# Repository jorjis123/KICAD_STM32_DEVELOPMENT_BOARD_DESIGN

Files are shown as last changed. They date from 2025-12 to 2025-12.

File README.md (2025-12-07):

Core MCU: STM32 with access to essential debug/programming interfaces (SWD/SWO/NRST, UART, I2C).

🔹 Power: USB input and dedicated 12V jack, with on-board buck converter for stable 3.3V supply.

🔹 Connectivity: Breakout headers for easy prototyping.

🔹 Layout focus: Optimized ground plane distribution, decoupling capacitors placed for noise reduction, and routing for signal integrity.

🔹 Applications: Ideal for embedded firmware development, educational use, and rapid prototyping.

This project gave me great hands-on experience in schematic capture, PCB layout, power distribution, and embedded hardware design best practices.

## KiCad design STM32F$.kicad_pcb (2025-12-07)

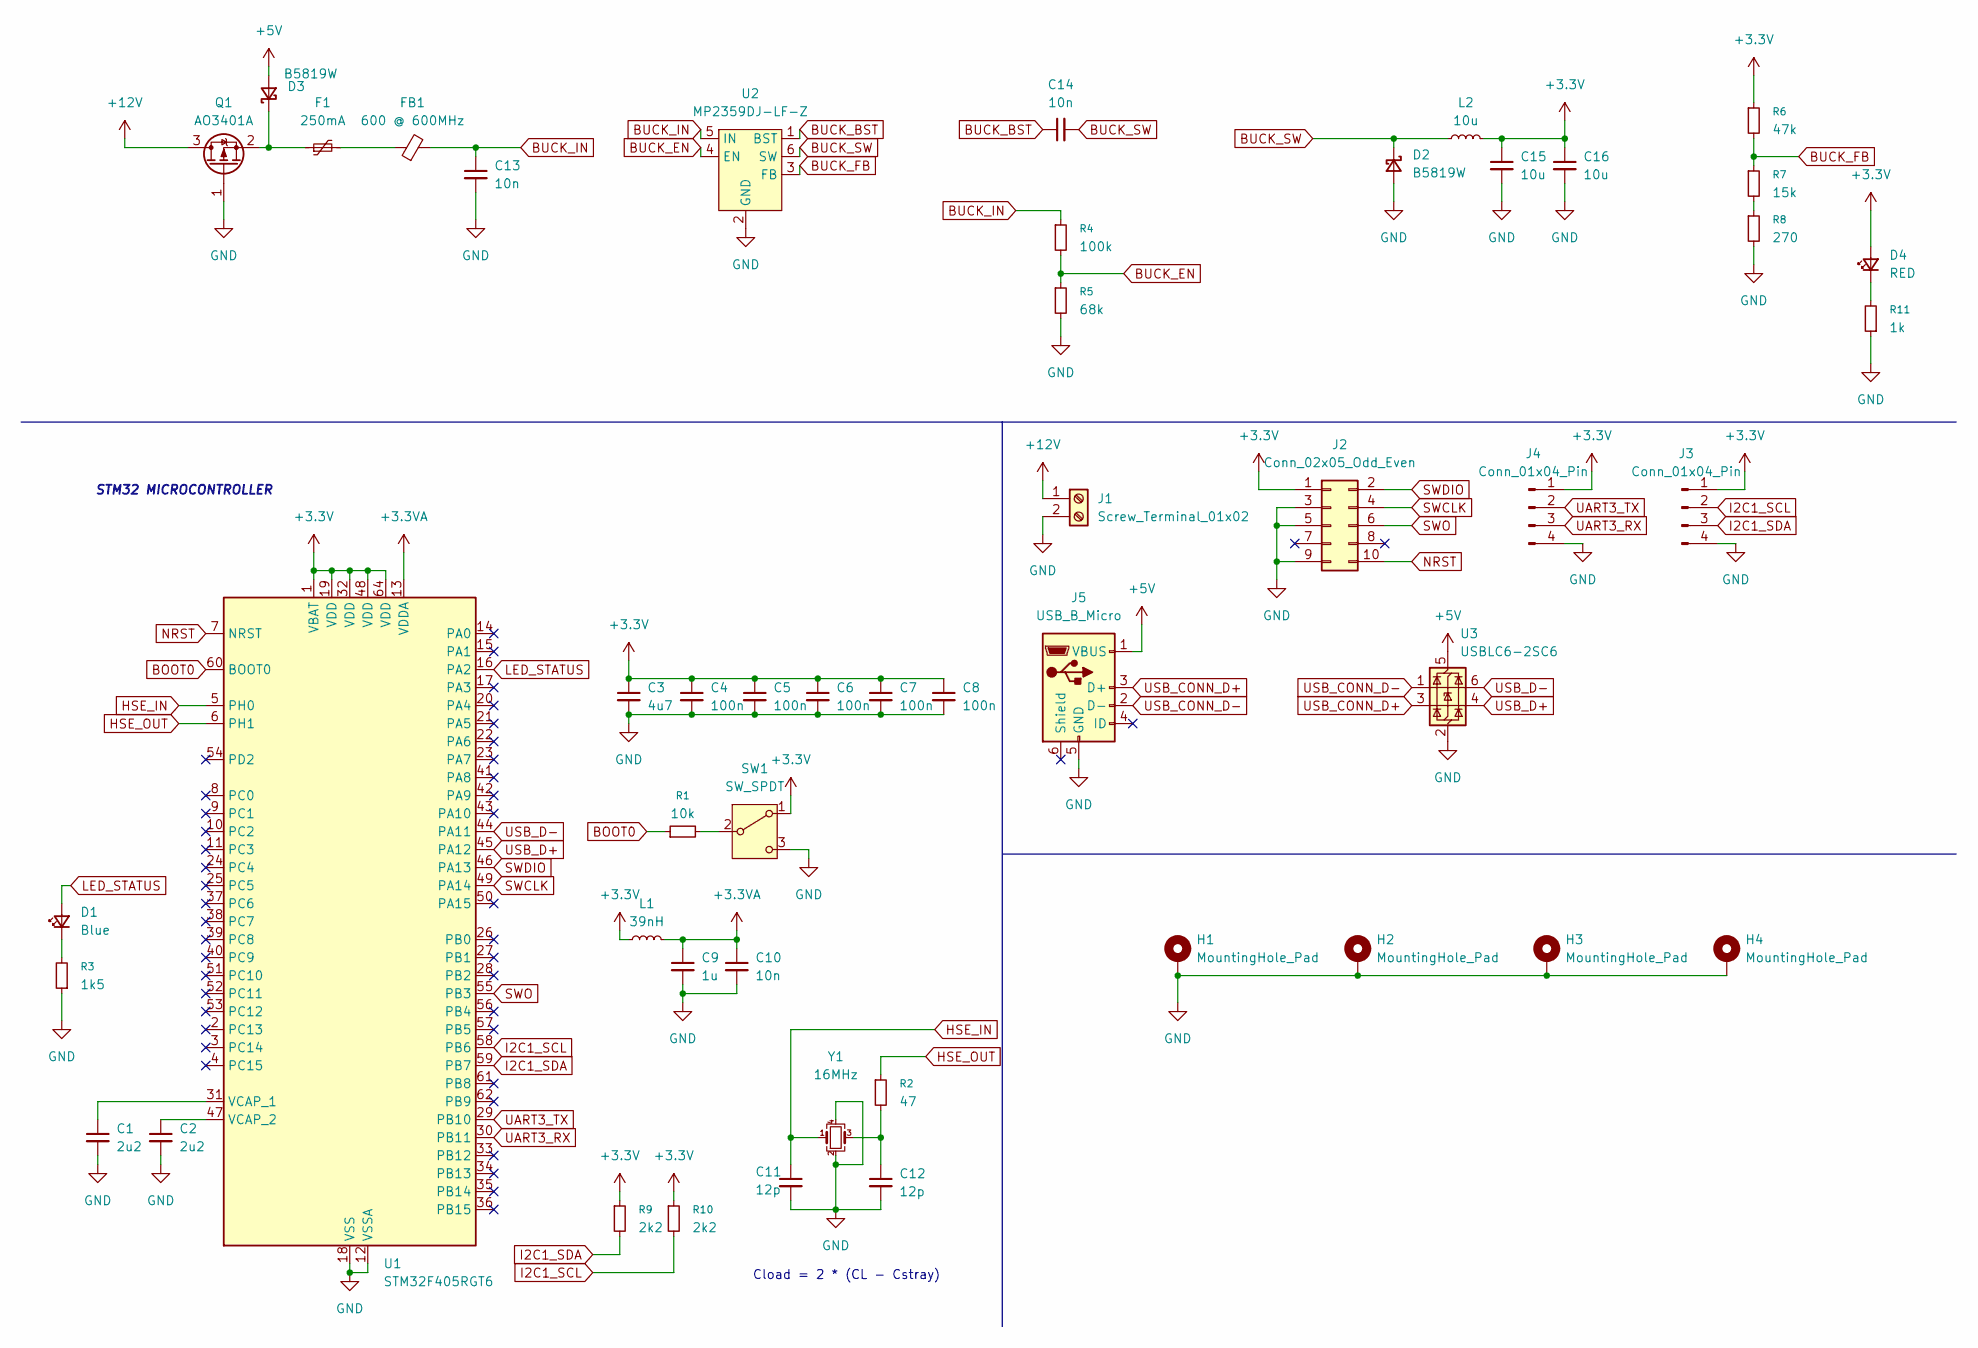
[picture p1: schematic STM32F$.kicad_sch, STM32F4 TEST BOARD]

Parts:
C1, C2: 2u2; C_0603_1608Metric
C3: 4u7; C_0603_1608Metric
C4, C5, C6, C7, C8: 100n; C_0402_1005Metric
C9: 1u; C_0402_1005Metric
C10: 10n; C_0402_1005Metric
C11, C12: 12p; C_0402_1005Metric
C13, C14: 10n; C_0603_1608Metric
C15, C16: 10u; C_1206_3216Metric
D1: Blue; LED_0603_1608Metric
D2, D3: B5819W; D_SOD-123
D4: RED; LED_0603_1608Metric
F1: 250mA; Fuse_1206_3216Metric
FB1: 600 @ 600MHz; L_0805_2012Metric
H1, H2, H3, H4: MountingHole_Pad; MountingHole_4.3mm_M4_Pad_Via
J1: Screw_Terminal_01x02; TerminalBlock_Phoenix_PT-1,5-2-3.5-H_1x02_P3.50mm_Horizontal
J2: Conn_02x05_Odd_Even; PinSocket_2x05_P1.27mm_Vertical_SMD
J3, J4: Conn_01x04_Pin; PinHeader_1x04_P1.00mm_Vertical
J5: USB_B_Micro; USB_Micro-B_Molex_47346-0001
L1: 39nH; L_0402_1005Metric
L2: 10u; L_Sunlord_SWPA8040S
Q1: AO3401A; SOT-23
R1: 10k; R_0603_1608Metric
R2: 47; R_0402_1005Metric
R3: 1k5; R_0603_1608Metric
R4: 100k; R_0402_1005Metric
R5: 68k; R_0402_1005Metric
R6: 47k; R_0402_1005Metric
R7: 15k; R_0603_1608Metric
R8: 270; R_0402_1005Metric
R9, R10: 2k2; R_0402_1005Metric
R11: 1k; R_0402_1005Metric
SW1: SW_SPDT; SW_SPDT_PCM12
U1: STM32F405RGT6; LQFP-64_10x10mm_P0.5mm
U2: MP2359DJ-LF-Z; SOT-23-6
U3: USBLC6-2SC6; SOT-23-6
Y1: 16MHz; Crystal_SMD_3225-4Pin_3.2x2.5mm

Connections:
+3.3V: C3.1, C4.1, C5.1, C6.1, C7.1, C8.1, C15.1, C16.1, D4.2 (A), J2.1, J3.1, J4.1, L1.1, L2.2, R6.1, R9.1, R10.1, SW1.1 (A), U1.1 (VBAT), U1.19 (VDD), U1.32 (VDD), U1.48 (VDD), U1.64 (VDD)
+3.3VA: C9.1, C10.1, L1.2, U1.13 (VDDA)
+5V: D3.2 (A), J5.1 (VBUS), U3.5 (VBUS)
+12V: J1.1, Q1.3 (D)
BOOT0: R1.1, U1.60 (BOOT0)
BUCK_BST: C14.1, U2.1 (BST)
BUCK_EN: R4.2, R5.1, U2.4 (EN)
BUCK_FB: R6.2, R7.1, U2.3 (FB)
BUCK_IN: C13.1, FB1.2, R4.1, U2.5 (IN)
BUCK_SW: C14.2, D2.1 (K), L2.1, U2.6 (SW)
GND: C1.2, C2.2, C3.2, C4.2, C5.2, C6.2, C7.2, C8.2, C9.2, C10.2, C11.2, C12.2, C13.2, C15.2, C16.2, D2.2 (A), H1.1, H2.1, H3.1, H4.1, J1.2, J2.3, J2.5, J2.9, J3.4, J4.4, J5.5 (GND), Q1.1 (G), R3.1, R5.2, R8.2, R11.1, SW1.3 (C), U1.12 (VSSA), U1.18 (VSS), U1.63 (VSS), U2.2 (GND), U3.2 (GND), Y1.2, Y1.4
HSE_IN: C11.1, U1.5 (PH0), Y1.1
HSE_OUT: R2.1, U1.6 (PH1)
I2C1_SCL: J3.2, R10.2, U1.58 (PB6)
I2C1_SDA: J3.3, R9.2, U1.59 (PB7)
LED_STATUS: D1.2 (A), U1.16 (PA2)
NRST: J2.10, U1.7 (NRST)
unnamed: C12.1, R2.2, Y1.3
unnamed: D1.1 (K), R3.2
unnamed: D3.1 (K), F1.1, Q1.2 (S)
unnamed: D4.1 (K), R11.2
unnamed: F1.2, FB1.1
unnamed: R7.2, R8.1
unnamed: R1.2, SW1.2 (B)
unnamed: C1.1, U1.31 (VCAP_1)
unnamed: C2.1, U1.47 (VCAP_2)
SWCLK: J2.4, U1.49 (PA14)
SWDIO: J2.2, U1.46 (PA13)
SWO: J2.6, U1.55 (PB3)
UART3_RX: J4.3, U1.30 (PB11)
UART3_TX: J4.2, U1.29 (PB10)
USB_CONN_D+: J5.3 (D+), U3.3 (I/O2)
USB_CONN_D-: J5.2 (D-), U3.1 (I/O1)
USB_D+: U1.45 (PA12), U3.4 (I/O2)
USB_D-: U1.44 (PA11), U3.6 (I/O1)

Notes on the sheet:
STM32 MICROCONTROLLER
Cload = 2 * (CL - Cstray)

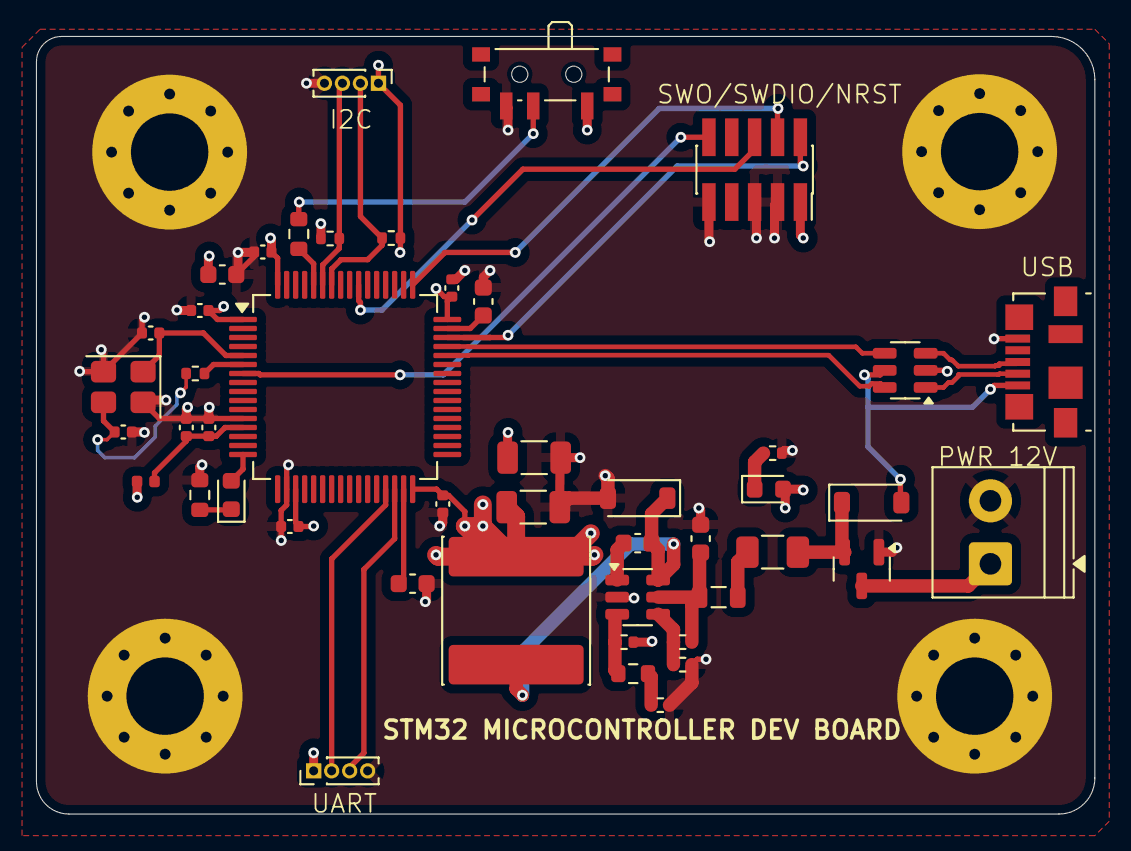
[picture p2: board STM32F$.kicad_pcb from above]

Board: 4 copper layers, 58.8 x 43.2 mm, 50 parts (0 on the bottom side), 35 nets.
